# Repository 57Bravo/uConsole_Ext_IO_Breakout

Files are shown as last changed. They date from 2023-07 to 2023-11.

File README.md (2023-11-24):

# uConsole External I/O Breakout - REV: A

## BEWARE!!! --- THIS DESIGN HAS NOT BEEN VERIFIED --- BEWARE!!!

This is a generic breakout board for ClockWorkPI's uConsole. I didn't order the cellular module, and wanted to use the external I/O slot. Here's the "REV: A" SWAG based off of renderings of the PCB.

I have not verified this design. Once I get the boards back from OshPark, stuffed, and tested on the uConsole; I'll tag a release. 

**Also, I don't work for CPI, and this is not an official board from them. I just threw their logo on there, since the uConsole is their gear. Show CPI some love, and checkout their products! :)**

https://www.clockworkpi.com/

https://github.com/clockworkpi/uConsole/blob/master/clockwork_Adapter_CM4_Schematic.pdf

https://github.com/clockworkpi/DevTerm/tree/main/Schematics

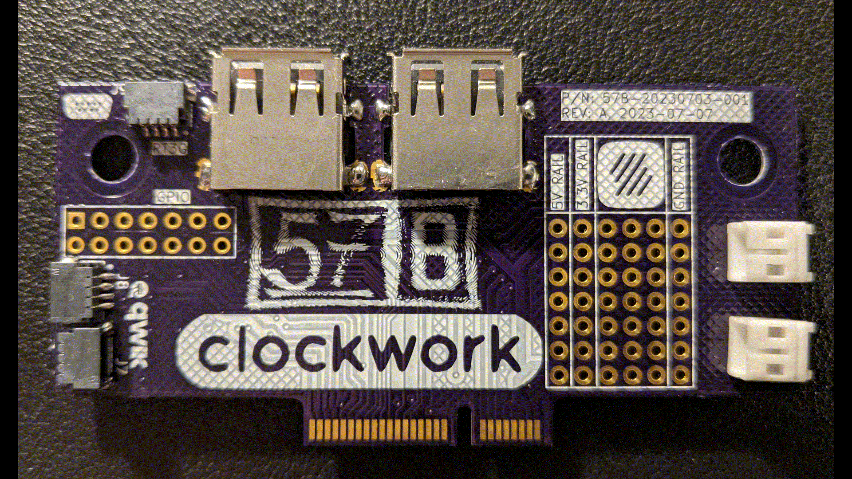
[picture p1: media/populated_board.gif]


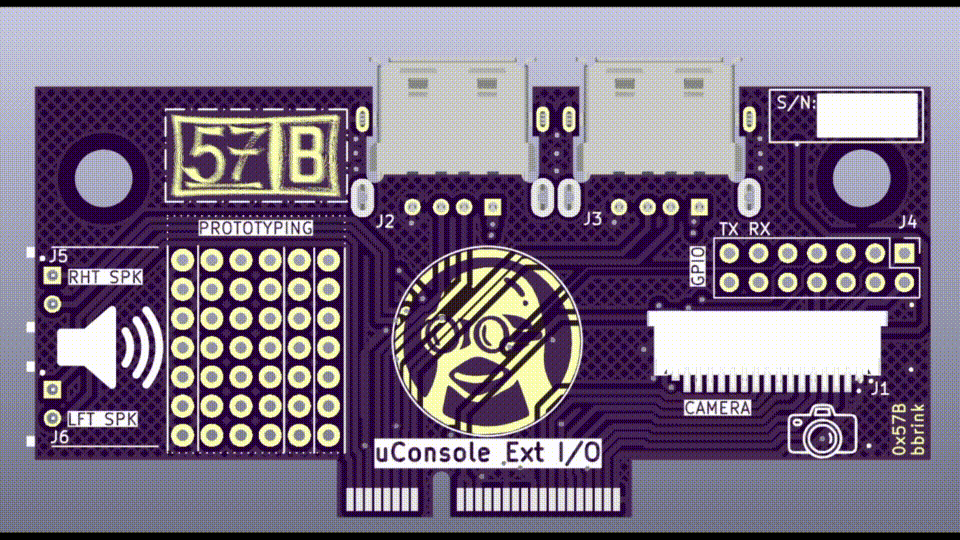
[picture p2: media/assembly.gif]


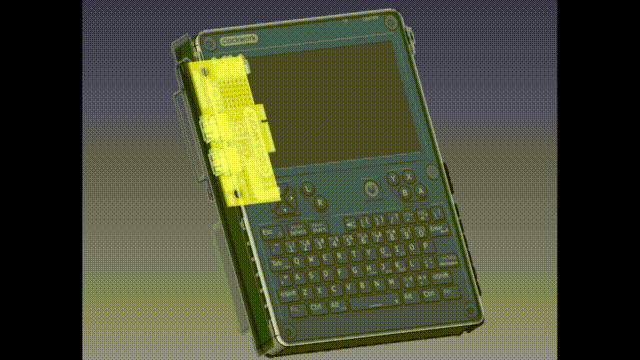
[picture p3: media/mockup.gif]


docs/schematic.pdf

## REV: A

**Epic fail on REV: A.**

When I made it, CPI hadn't released the DXF for the 4G card yet. I had to eyeball the board outline based on the website images. I missed the outer edge by 1mm. 

Luckily the edge was just ground plane, and I was able to file the FR4 back to get it to fit. Continuity checks out, but.... I think a REV: B is in order ha.

The fixes for REV: B are:
* fix the board outline to account for the thicker enclosure wall
* refactor the audio so that the onboard speakers can be used instead of the JSTs
* flip the QWIIC connectors so they don't interfere with the speaker housings
* pull the USB connectors in a little so they're flush with the enclosure wall

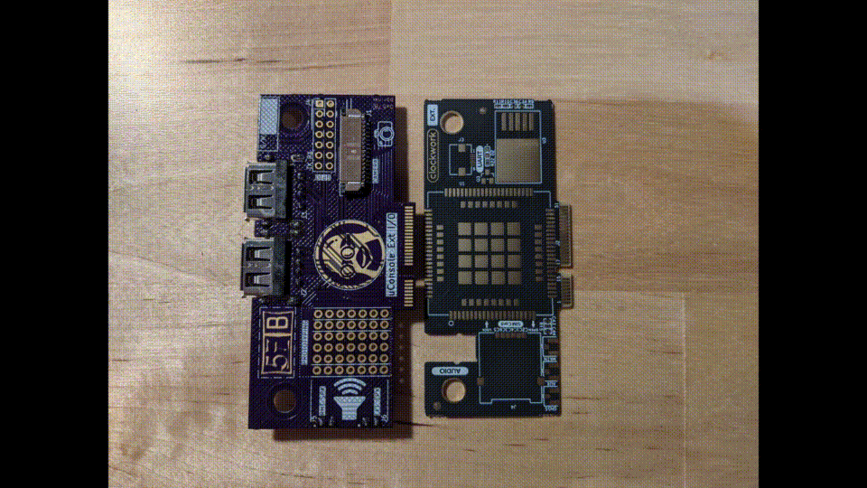
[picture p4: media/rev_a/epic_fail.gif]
Epic Fail


## Notes

### Other boards made by Quadbit (Vitaly Domnikov), that you can buy on Tindie

* [uPico](https://www.tindie.com/products/quadbit/upico/)
  * [Src](https://github.com/dotcypress/upico)
* [uHub](https://www.tindie.com/products/quadbit/uhub/)
  * [Src](https://github.com/dotcypress/uhub)

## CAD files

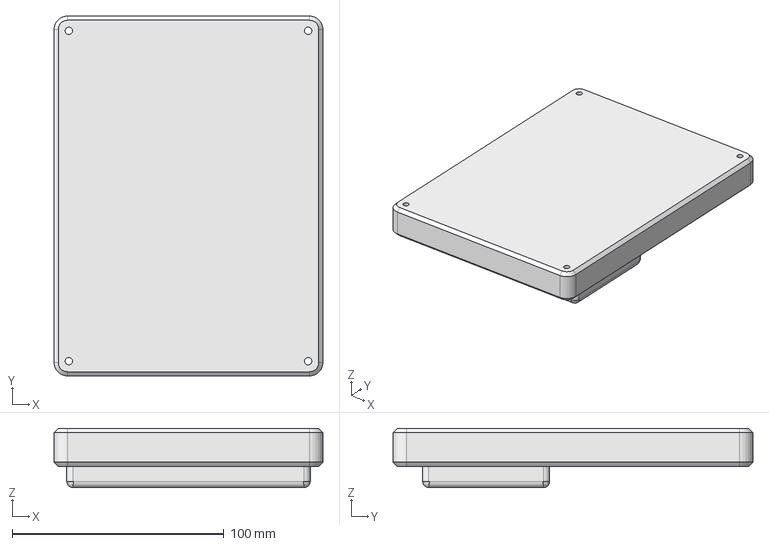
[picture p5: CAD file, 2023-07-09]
cad/mockups.FCStd
127.0 x 170.0 x 28.0 mm
mini_pcie

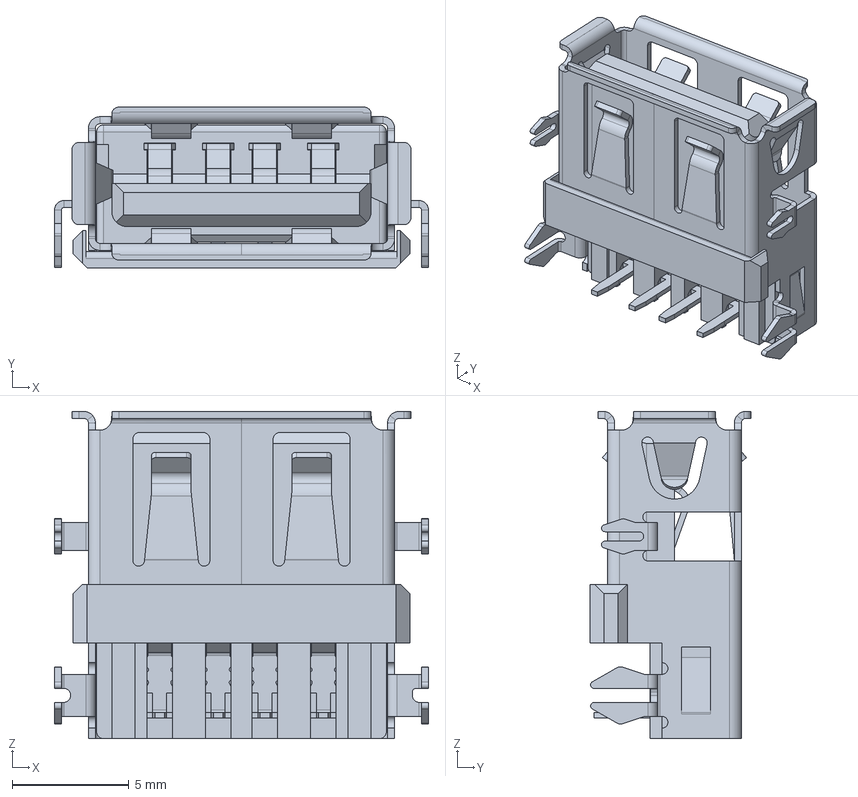
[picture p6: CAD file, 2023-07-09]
pcb/ext_pcb/models/GSB12J21C1EU.step
16.0 x 6.88 x 14.0 mm

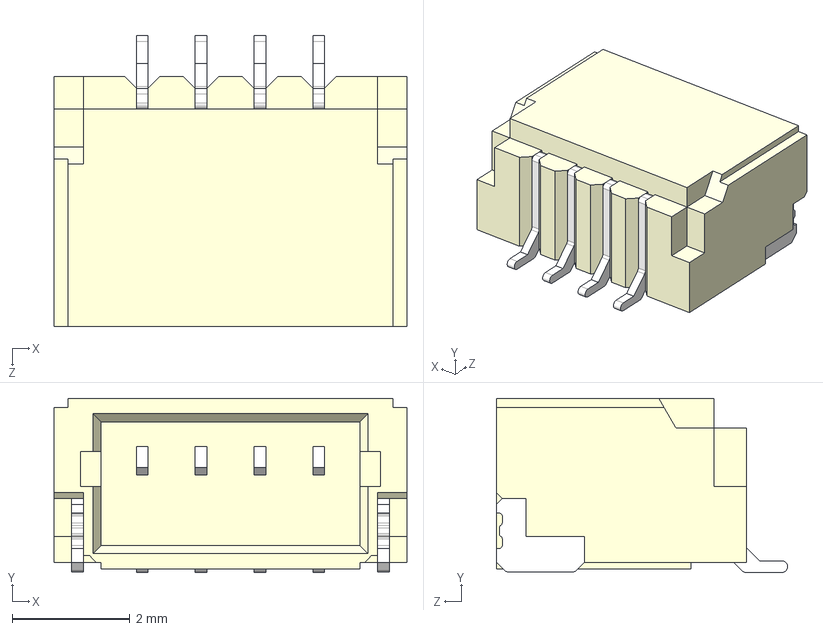
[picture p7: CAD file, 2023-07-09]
pcb/ext_pcb/models/SM04B-SRSS-TB_LF__SN_.step
6.00 x 2.96 x 4.95 mm

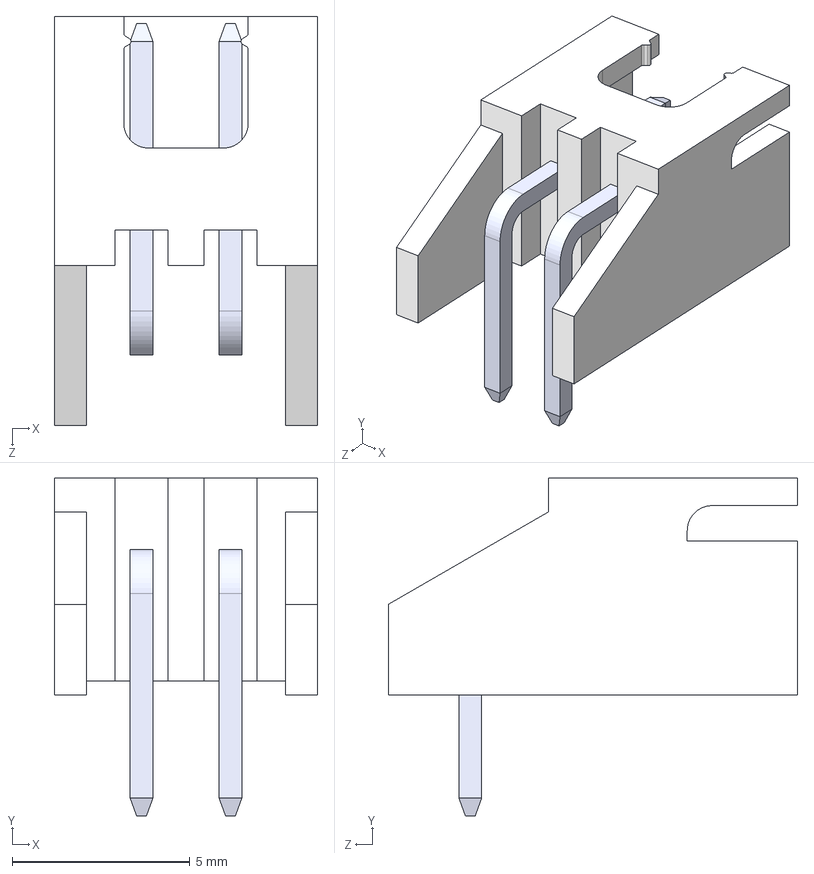
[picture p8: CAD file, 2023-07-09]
pcb/ext_pcb/models/S2B-XH-A_LF__SN_.step
7.40 x 9.50 x 11.5 mm

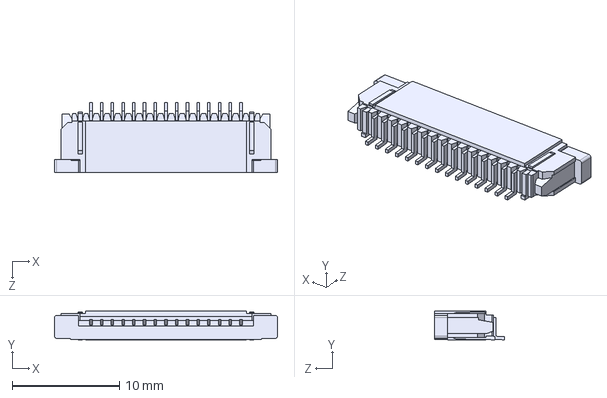
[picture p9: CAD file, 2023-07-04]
pcb/ext_pcb/models/SFW15R-2STE1LF.step
20.8 x 2.70 x 6.50 mm

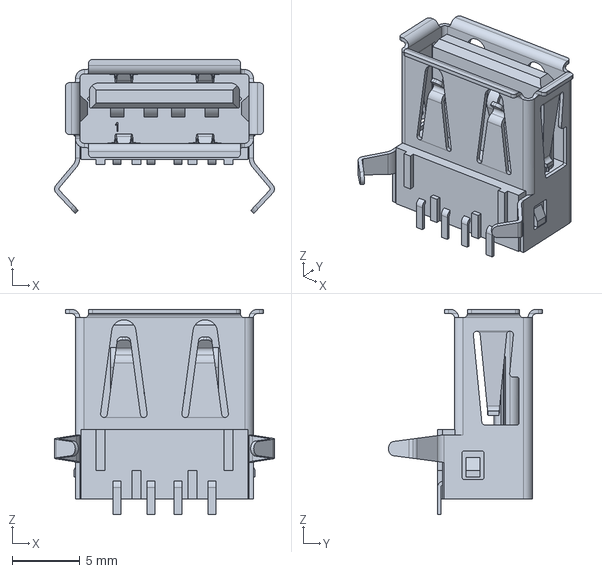
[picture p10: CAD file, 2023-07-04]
pcb/ext_pcb/models/292303-7.step
16.2 x 11.4 x 15.2 mm

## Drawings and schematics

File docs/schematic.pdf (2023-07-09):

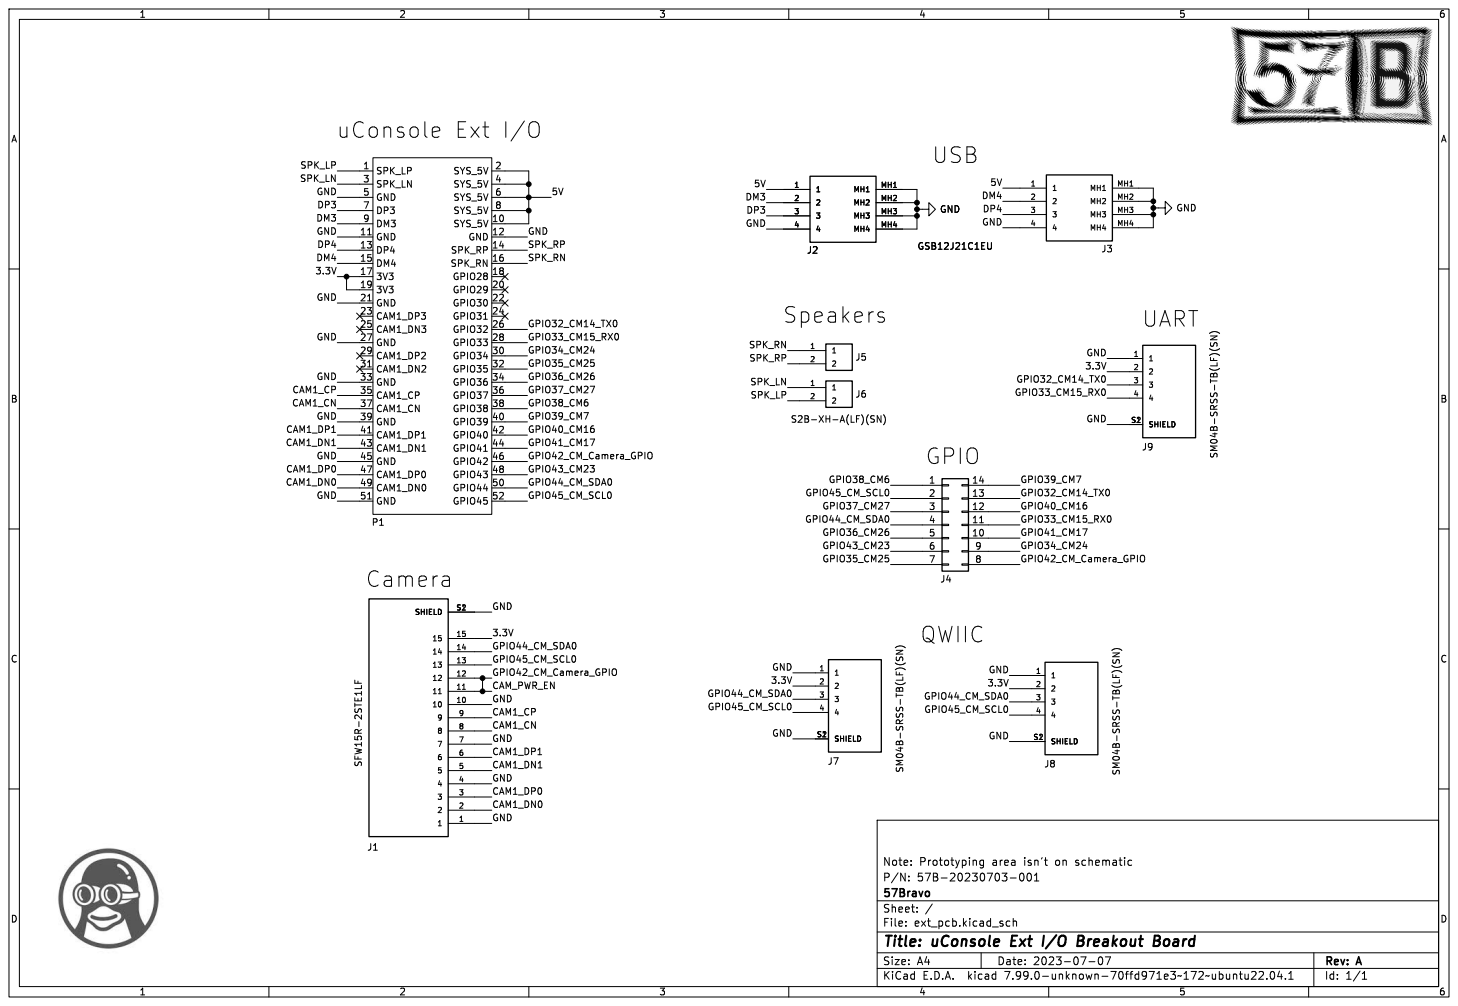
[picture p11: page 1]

Id: 1/1 Title: uConsole Ext I/O Breakout Board

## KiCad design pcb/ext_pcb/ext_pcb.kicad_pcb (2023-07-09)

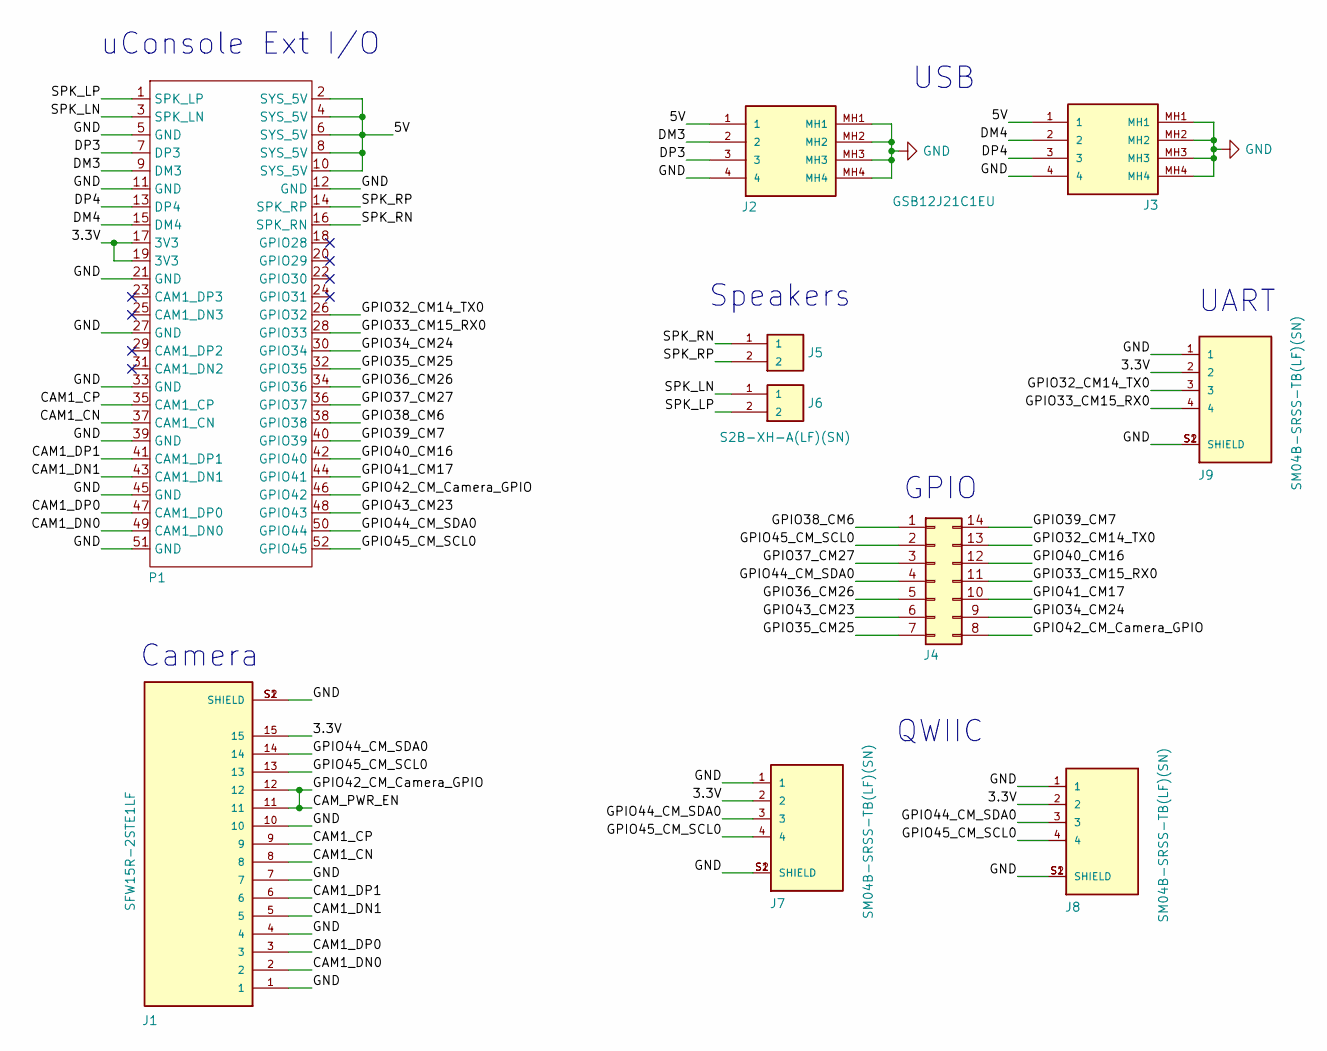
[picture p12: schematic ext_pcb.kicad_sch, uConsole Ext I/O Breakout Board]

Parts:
J1: SFW15R-2STE1LF; AMPHENOL_SFW15R-2STE1LF; PARTREV AE
J2, J3: GSB12J21C1EU; MOUSER_PART_NUMBER 523-GSB12J21C1EU
J4: Conn_02x07_Counter_Clockwise; PinHeader_2x07_P2.54mm_Vertical
J5, J6: S2B-XH-A(LF)(SN); JST_S2B-XH-A(LF)(SN)
J7, J8, J9: SM04B-SRSS-TB(LF)(SN); JST_SM04B-SRSS-TB(LF)(SN)
P1: ext_card_fp

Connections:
/3.3V: J1.15, J7.2, J8.2, J9.2, P1.17 (3V3), P1.19 (3V3)
/5V: J2.1, J3.1, P1.2 (SYS_5V), P1.4 (SYS_5V), P1.6 (SYS_5V), P1.8 (SYS_5V), P1.10 (SYS_5V)
/CAM1_CN: J1.8, P1.37 (CAM1_CN)
/CAM1_CP: J1.9, P1.35 (CAM1_CP)
/CAM1_DN0: J1.2, P1.49 (CAM1_DN0)
/CAM1_DN1: J1.5, P1.43 (CAM1_DN1)
/CAM1_DP0: J1.3, P1.47 (CAM1_DP0)
/CAM1_DP1: J1.6, P1.41 (CAM1_DP1)
/CAM_PWR_EN: J1.11, J1.12, J4.8, P1.46 (GPIO42)
/DM3: J2.2, P1.9 (DM3)
/DM4: J3.2, P1.15 (DM4)
/DP3: J2.3, P1.7 (DP3)
/DP4: J3.3, P1.13 (DP4)
/GPIO32_CM14_TX0: J4.13, J9.3, P1.26 (GPIO32)
/GPIO33_CM15_RX0: J4.11, J9.4, P1.28 (GPIO33)
/GPIO34_CM24: J4.9, P1.30 (GPIO34)
/GPIO35_CM25: J4.7, P1.32 (GPIO35)
/GPIO36_CM26: J4.5, P1.34 (GPIO36)
/GPIO37_CM27: J4.3, P1.36 (GPIO37)
/GPIO38_CM6: J4.1, P1.38 (GPIO38)
/GPIO39_CM7: J4.14, P1.40 (GPIO39)
/GPIO40_CM16: J4.12, P1.42 (GPIO40)
/GPIO41_CM17: J4.10, P1.44 (GPIO41)
/GPIO43_CM23: J4.6, P1.48 (GPIO43)
/GPIO44_CM_SDA0: J1.14, J4.4, J7.3, J8.3, P1.50 (GPIO44)
/GPIO45_CM_SCL0: J1.13, J4.2, J7.4, J8.4, P1.52 (GPIO45)
/SPK_LN: J6.1, P1.3 (SPK_LN)
/SPK_LP: J6.2, P1.1 (SPK_LP)
/SPK_RN: J5.1, P1.16 (SPK_RN)
/SPK_RP: J5.2, P1.14 (SPK_RP)
GND: J1.1, J1.4, J1.7, J1.10, J1.S1 (SHIELD), J1.S2 (SHIELD), J2.4, J2.MH1, J2.MH2, J2.MH3, J2.MH4, J3.4, J3.MH1, J3.MH2, J3.MH3, J3.MH4, J7.1, J7.S1 (SHIELD), J7.S2 (SHIELD), J8.1, J8.S1 (SHIELD), J8.S2 (SHIELD), J9.1, J9.S1 (SHIELD), J9.S2 (SHIELD), P1.5 (GND), P1.11 (GND), P1.12 (GND), P1.21 (GND), P1.27 (GND), P1.33 (GND), P1.39 (GND), P1.45 (GND), P1.51 (GND)

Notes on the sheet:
GPIO
QWIIC
Camera
USB
uConsole Ext I/O
Speakers
UART

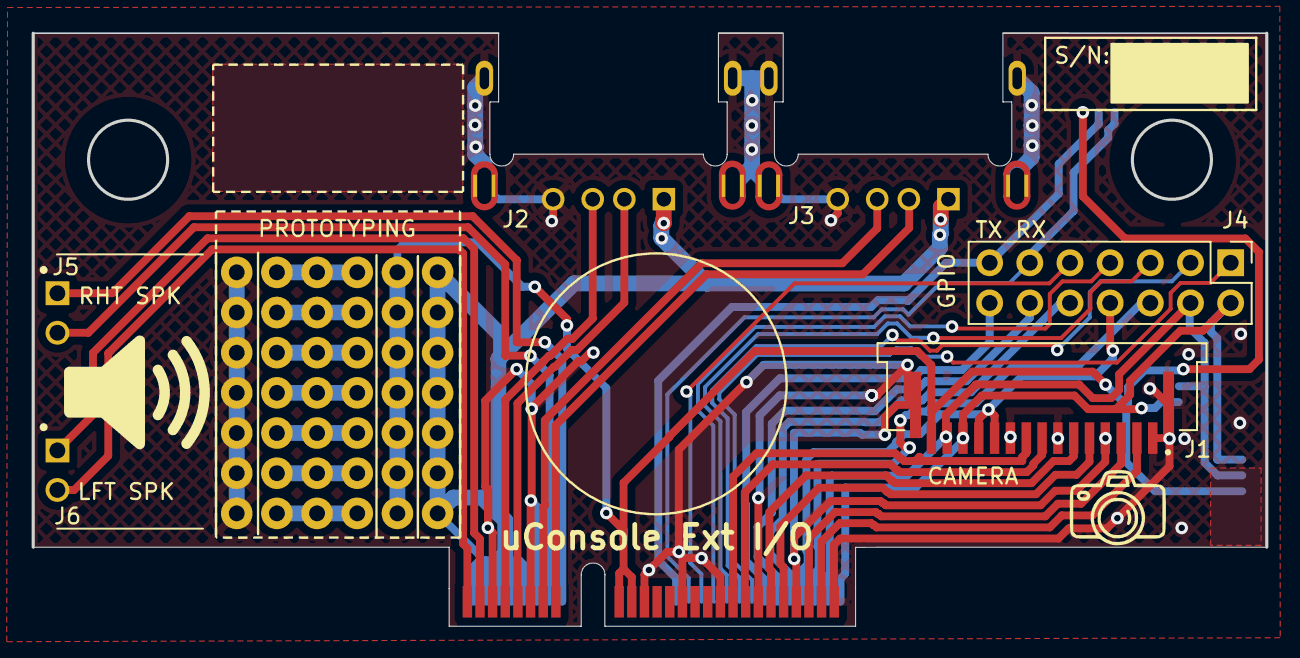
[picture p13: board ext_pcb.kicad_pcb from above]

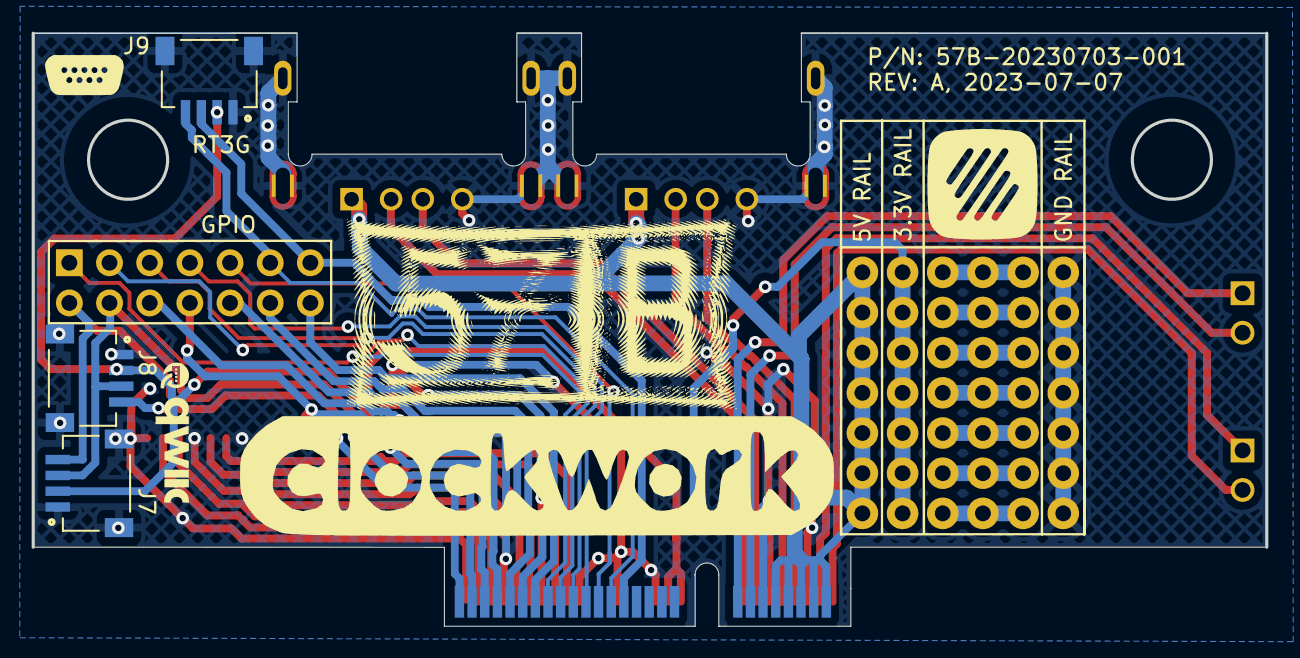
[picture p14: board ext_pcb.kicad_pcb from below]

Board: 2 copper layers, 78.0 x 37.5 mm, 10 parts (5 on the bottom side), 31 nets.

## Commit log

2023-07-04 export to GitHub
    [292303-7.step, SFW15R-2STE1LF.step, ext_pcb.kicad_pcb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]
2023-07-09 REV: A
    [GSB12J21C1EU.step, S2B-XH-A_LF__SN_.step, SM04B-SRSS-TB_LF__SN_.step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]
2023-07-25 added photo of populated board
2023-11-24 added notes on other expansion boards
